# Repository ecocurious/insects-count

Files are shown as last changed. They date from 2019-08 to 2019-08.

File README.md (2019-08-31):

## Insektencounter
Ziel dieses Projekts ist die Entwicklung eines Geräts zur Erkennung und Zählung verschiedener Insektenarten.
Damit soll es dann möglich sein, die Artenvielfalt und deren Veränderung engmaschig und lokal zu erfassen. Zusammen mit anderen Umweltdaten kann so eine Karte erstellt werden. 

Dazu wurden zwei Verfahren ausgewählt, um die Insekten erkennen und somit auch zählen zu können.
- optisch mit Hilfe einer Kamera, die Erkennung erfolgt hier mit auf Insekten trainierter KI
- [Erkennung des Flügelschlags mit einem optischen Mikrofon](http://msei.github.io/insects-count/fluegelschlag.html)

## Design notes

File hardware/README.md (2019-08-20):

Insect Counter Hardware
=======================

## IR-Transmitter

PCB for modulated IR LED transmitter

## IR-Receiver

PCB to receive modulated IR signal

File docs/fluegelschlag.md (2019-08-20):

# Klassifizierung von Insekten an Hand des Flügelschlags

Insekten eines Typs und Geschlechts haben sehr ähnliche Flügelschläge in Winkel und Frequenz. Da ihre (unverletzten) Flügel auch ähnlich gebaut sind hören sie sich auch sehr ähnlich an (harmonische Oberwellen). Ausnahmen sind Männchen einiger Mosquitoarten, die in der Paarungszeit den Klang der Weibchen, das die umwerben, immitieren.
[Insect-flight](https://en.wikipedia.org/wiki/Insect_flight)

Der Flügelschlag kann mit verschiedenen Verfahren vermessen werden. Akustisch durch Schall oder Licht, Radar, Highspeedkamera mit Bildverarbeitung

[Spitzen, Jeroen & Takken, Willem. (2018). Keeping track of mosquitoes: A review of tools to track, record and analyse mosquito flight. Parasites & Vectors. 11. 10.1186/s13071-018-2735-6. ](https://parasitesandvectors.biomedcentral.com/articles/10.1186/s13071-018-2735-6)

### Akustisches Mikrofon
Die passive, schallbasierte Vermessung des Flügelschlags ist sehr störungsbehaftet außerhalb des Labors. Wind und Reflektionen von anderen Tieren erzeugen breitbandige Störungen, die schwer zu entfernen sind. Somit ist es schwer, das eigentliche Nutzsignal zu isolieren. Fledermäuse nutzen daher aktive Echolokation und Erkennung, indem sie ein definiertes Signal aussenden und dieses Muster mit dem empfangenen Signal überlagern, um das Nutzsignal vom Hintergrundgreräusch trennen zu können.Ähnlich funktionieren auch moderne Radarsysteme. Je nach Verhalten des ausgesandten Signals können unterschiedliche Charakteristika an Beute und Umgebung erkannt werden. [Animal-echolocation](https://en.wikipedia.org/wiki/Animal_echolocation)

### Optisches Mikrofon
Strahlt man Licht auf ein fliegendes Insekt, so hat der Flügelschlag Einfluss auf die Intensität des Lichts hinter dem Insekt, da durch den sich ändernden Anstellwinkel der Flügel mal mehr oder weniger Licht abgeschattet wird. Ebenso ist das auch mit dem reflektierten Licht. Diese Helligkeitsschwankungen können durch einen Photodetektor gemessen werden. Niederfrequente Änderungen, die durch Sonnenlicht oder die Bewegung des Körpers hervorgerufen werden,lassen sich gut ausfiltern. Das erzeugte Signal hat eine Bandbreite im einstelligen kHZ Bereich und kann so mit günstigen Mikrocontrollern erfasst und verarbeitet werden. 

Zu zeigen: 
* eventuell auch Erkennung auf µC möglich mit Bayes
* horizontale oder vertikale Messung robuster

[Chen, Y., Why, A., Batista, G., Mafra-Neto, A., Keogh, E. Flying Insect Detection and Classification with Inexpensive Sensors. J. Vis. Exp. (92), e52111, doi:10.3791/52111 (2014).](https://arxiv.org/abs/1403.2654v1)

[Keogh, E.,Naive Bayes Classifier](https://www.cs.ucr.edu/~eamonn/CE/Bayesian%20Classification%20withInsect_examples.pdf)

[MDPI and ACS Style
Sandrini Moraes, F.; Edson Nava, D.; Scheunemann, T.; Santos da Rosa, V. Development of an Optoelectronic Sensor for Detecting and Classifying Fruit Fly (Diptera: Tephritidae) for Use in Real-Time Intelligent Traps. Sensors 2019, 19, 1254.](https://www.mdpi.com/1424-8220/19/5/1254/htm)

[Potamitis I, Rigakis I, Fysarakis K (2015)
Insect Biometrics: Optoacoustic Signal Processing
and Its Applications to Remote Monitoring of McPhail
Type Traps. PLoS ONE 10(11): e0140474.
doi:10.1371/journal.pone.0140474](https://pdfs.semanticscholar.org/1b32/68c05733fc8ac109b37251a67e5672cd6d9b.pdf)

[Rigakis, Iraklis & Potamitis, Ilyas & Tatlas, Nicolaos-Alexandros & Livadaras, Ioannis & Ntalampiras, Stavros. (2019). A Multispectral Backscattered Light Recorder of Insects’ Wingbeats. Electronics. 8. 277. 10.3390/electronics8030277. ](https://www.mdpi.com/2079-9292/8/3/277/htm)

[Michael A B Deakin, Formulae for insect wingbeat frequency, Journal of Insect Science, Volume 10, Issue 1, 2010, 96](https://doi.org/10.1673/031.010.9601)

[I. Potamitis and I. Rigakis, "Large Aperture Optoelectronic Devices to Record and Time-Stamp Insects’ Wingbeats," in IEEE Sensors Journal, vol. 16, no. 15, pp. 6053-6061, Aug.1, 2016.
doi: 10.1109/JSEN.2016.2574762](https://ieeexplore.ieee.org/document/7482663)

### Radar

In der Radartechnik wurde die Erkennung eines Flugzeugtyps durch Vermessung der Turbinenschaufeln und deren Drehzahl oder die Erkennung von Personen anhand ihres Gangs entwickelt. Hierbei wird der Umstand ausgenutzt, dass Teile des zu vermessenden Objekts relativ zum Großteil des Objekts bewegen (Beine und Arme). Bewegt sich das zu vermessende Objekt ebenfalls, so überlagert sich die relative Bewegung mit der globalen Bewegung. Bei den häufig eigesetzten Dopplerradaren wird dies durch eine periodische Änderung der Ausgangsfrequenz deutlich. Dabei ist die Grundfrequenz proportional zur Fluggeschindigkeit, relativ zum Radar und die Periodendauer der Frequenzänderungen entspricht der relativen Bewegung. Diese Frequenzänderung wird auch als Microdoppler bezeichnet. 
Dieses Verfahren kann auch zur Erkennung des Flügelschlags verwendet werden. Da Radare empfindlich auf sie zu oder von ihnen weg bewegenden Objekten reagieren, sollte der Radar in der Flugebene des Insekts sein.
Auch hier muss das Nutzsignal herausgefiltert werden. Neben der Frequenzmodulation durch den Flügel kann auch die Phasenmodulation verwendet werden, da diese auch periodisch moduliert wird durch den Flügelschlag. Hierzu braucht man neben dem reellen in-Phasesignal noch das imaginäre Q-Signal des Radars. Günstige Geräte führen dies meist nicht nach außen. Auch die das Arbeitsfrequenzband hat einen Einfluss auf das Ergebnis.

[Wang, R., Hu, C., Fu, X., Long, T., & Zeng, T. (2017). Micro-Doppler measurement of insect wing-beat frequencies with W-band coherent radar. Scientific reports, 7(1), 1396. doi:10.1038/s41598-017-01616-4](https://www.ncbi.nlm.nih.gov/pmc/articles/PMC5431090/)

### Highspeed Bildverarbeitung

Die Aufnahme eines fliegenden Insekts mittels einer Highspeedkamera, lässt auch Rückschlüsse auf die Schlagfrequenz zu. Diese Kameras brauchen wegen der kurzen Belichtungszeit des Bilder eine ausreichend starke Beleuchtung. Auch sind diese Kameras und die Hardware zur Verarbeitung der Bilder vergleichsweise teurer als die oben genannten Methoden. Daher wird dieses Verfahren zunächst nicht weiter verfolgt.

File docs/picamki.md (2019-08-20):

# Insektenerkennung mit Kamera und KI

Hier soll mit Hilfe eines RaspberryPi und den dafür verfügbaren Kameras ein Insekt fotografiert und per KI charakterisiert werden.

## Aufbau

## Vorgehen

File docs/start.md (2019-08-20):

## Insektencounter
Ziel dieses Projekts ist die Entwicklung eines Geräts zur Erkennung und Zählung verschiedener Insektenarten.
Damit soll es dann möglich sein, die Artenvielfalt und deren Veränderung engmaschig und lokal erfassen zu können. Zusammen mit anderen Umweltdaten kann so eine Karte erstellt werden. Auch kann so die Ausbreitung invasiver Arten erfasst und verfolgt werden.

Dazu wurden zwei Verfahren ausgewählt, um die Insekten erkennen und somit auch zählen zu können.
- [optisch mit Hilfe einer Kamera, die Erkennung erfolgt hier mit auf Insekten trainierter KI](http://msei.github.io/insects-count/picamki.html)
- [Erkennung des Flügelschlags mit einem optischen Mikrofon](http://msei.github.io/insects-count/fluegelschlag.html)

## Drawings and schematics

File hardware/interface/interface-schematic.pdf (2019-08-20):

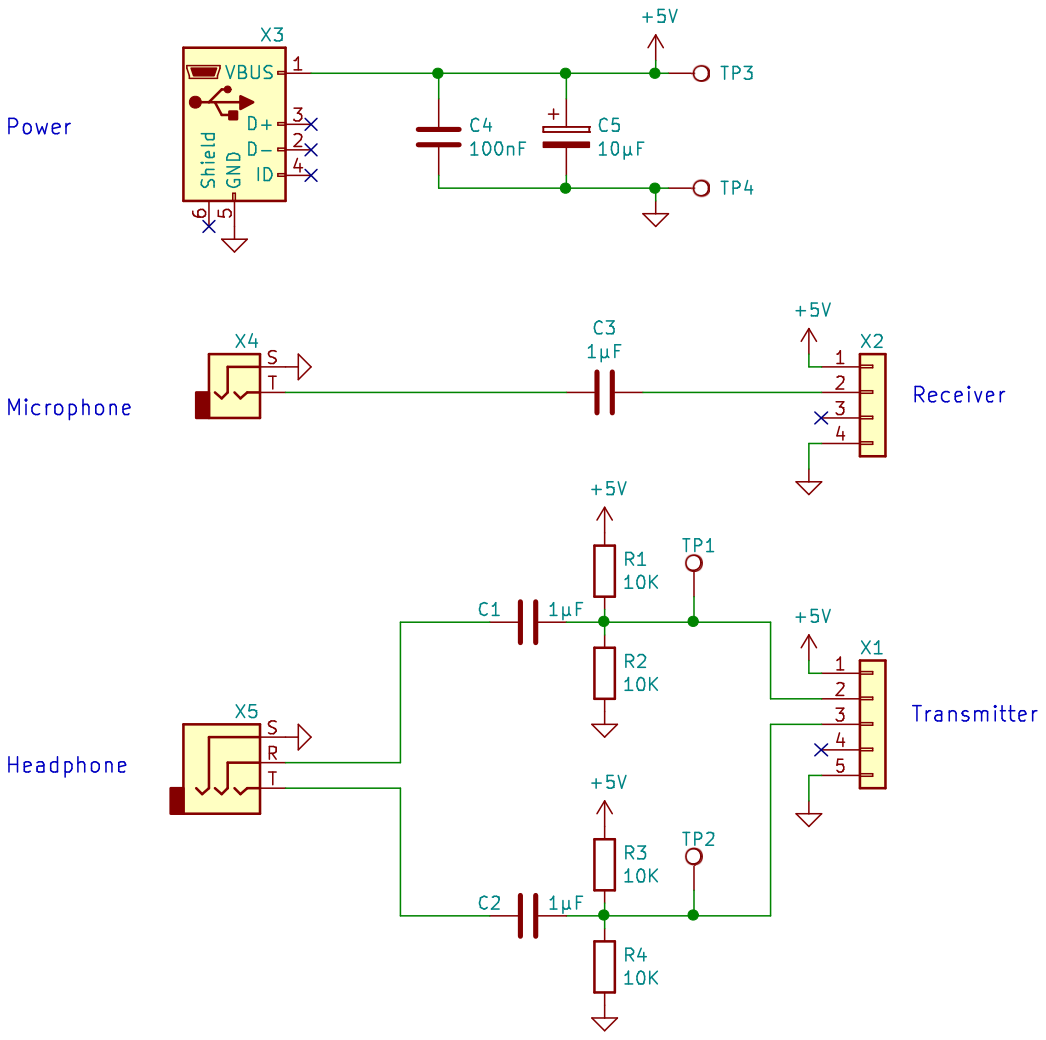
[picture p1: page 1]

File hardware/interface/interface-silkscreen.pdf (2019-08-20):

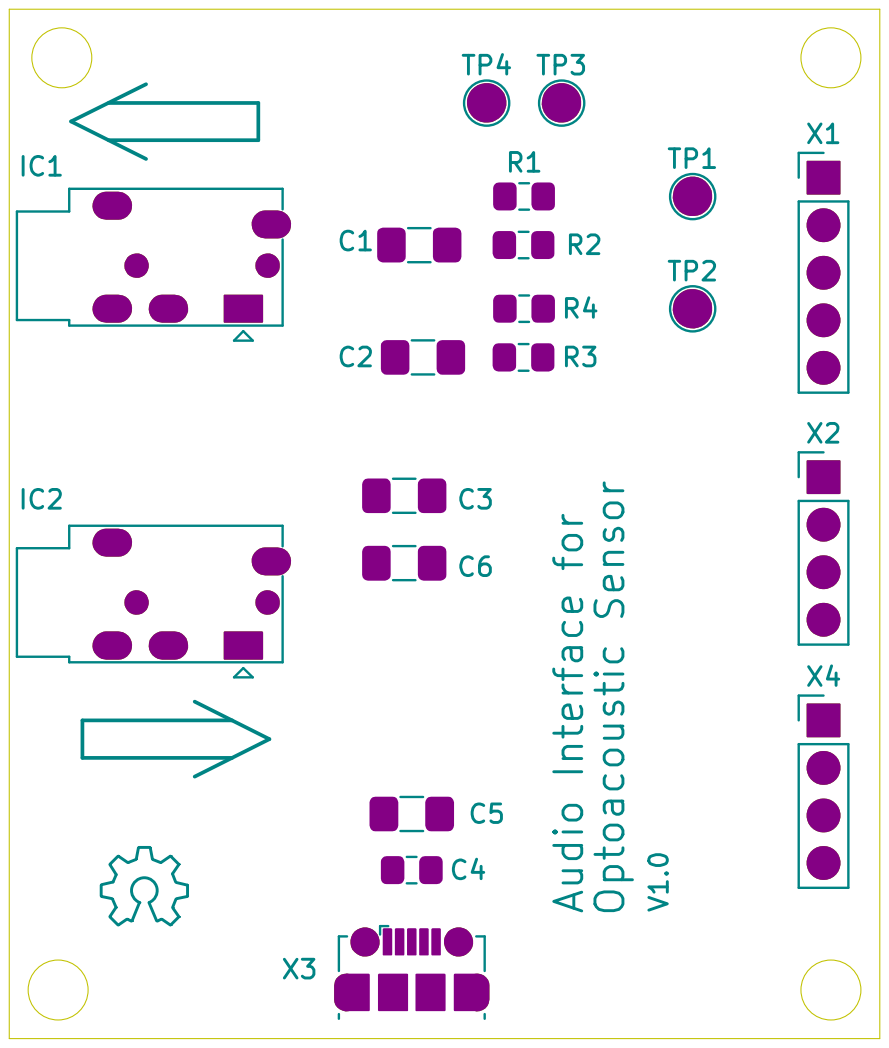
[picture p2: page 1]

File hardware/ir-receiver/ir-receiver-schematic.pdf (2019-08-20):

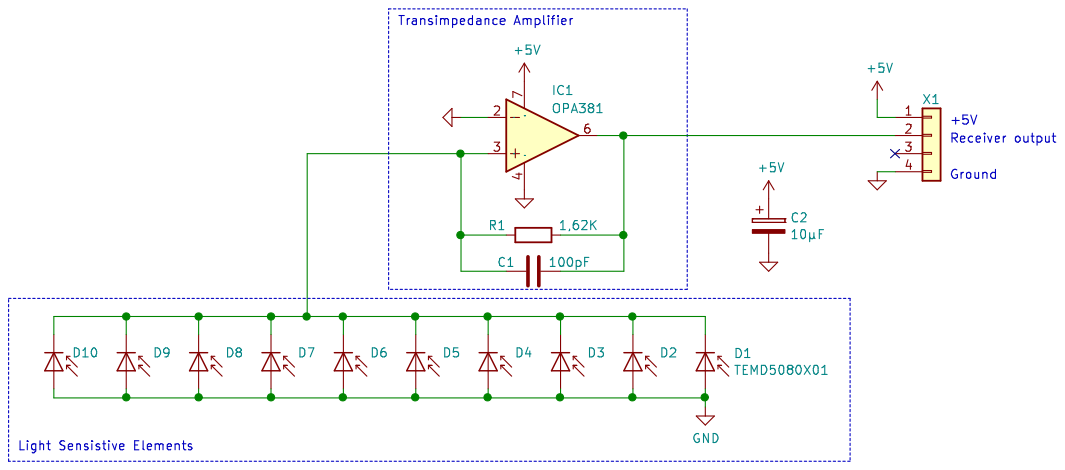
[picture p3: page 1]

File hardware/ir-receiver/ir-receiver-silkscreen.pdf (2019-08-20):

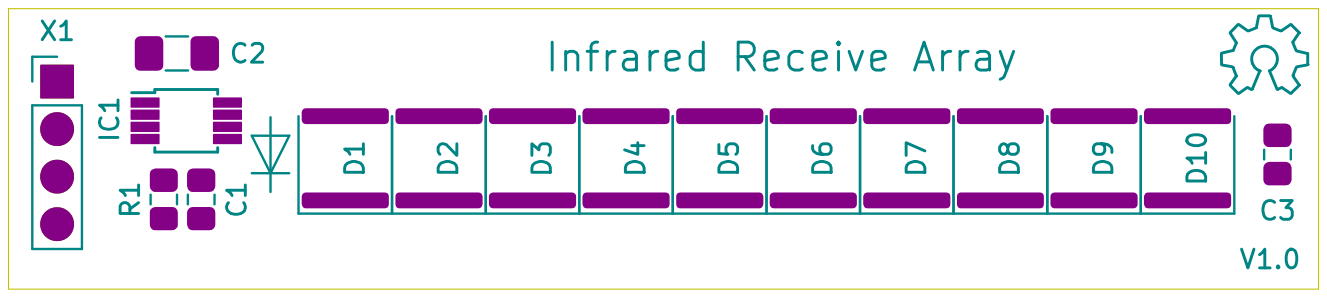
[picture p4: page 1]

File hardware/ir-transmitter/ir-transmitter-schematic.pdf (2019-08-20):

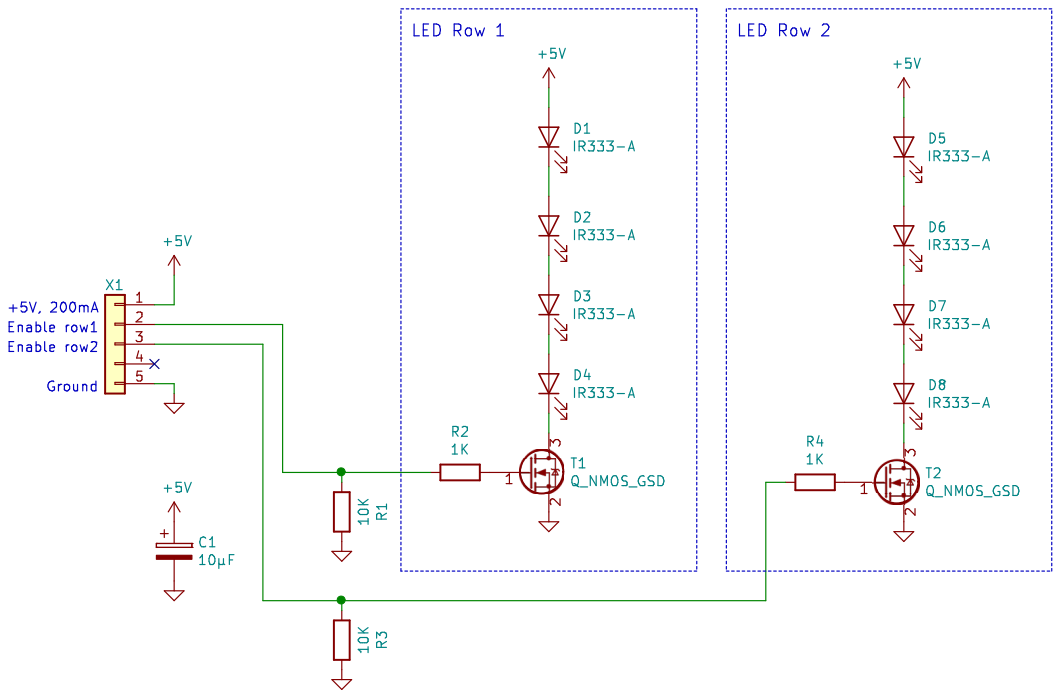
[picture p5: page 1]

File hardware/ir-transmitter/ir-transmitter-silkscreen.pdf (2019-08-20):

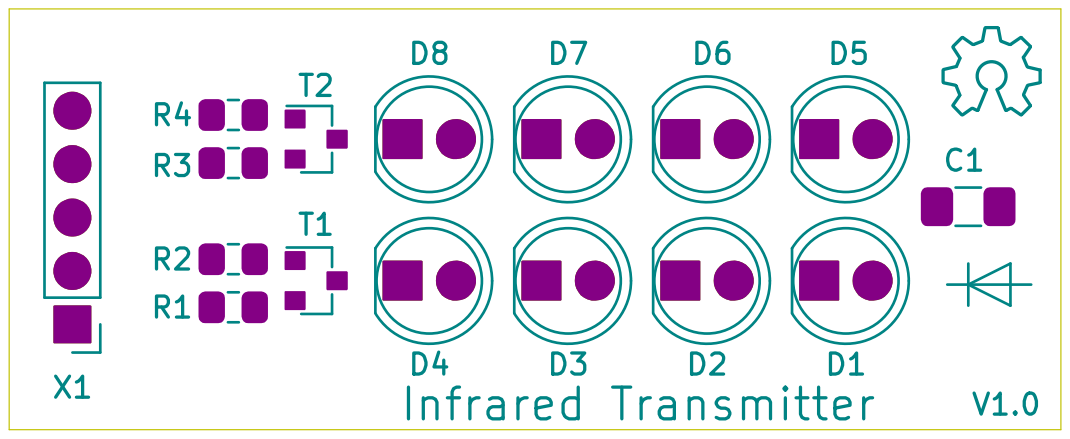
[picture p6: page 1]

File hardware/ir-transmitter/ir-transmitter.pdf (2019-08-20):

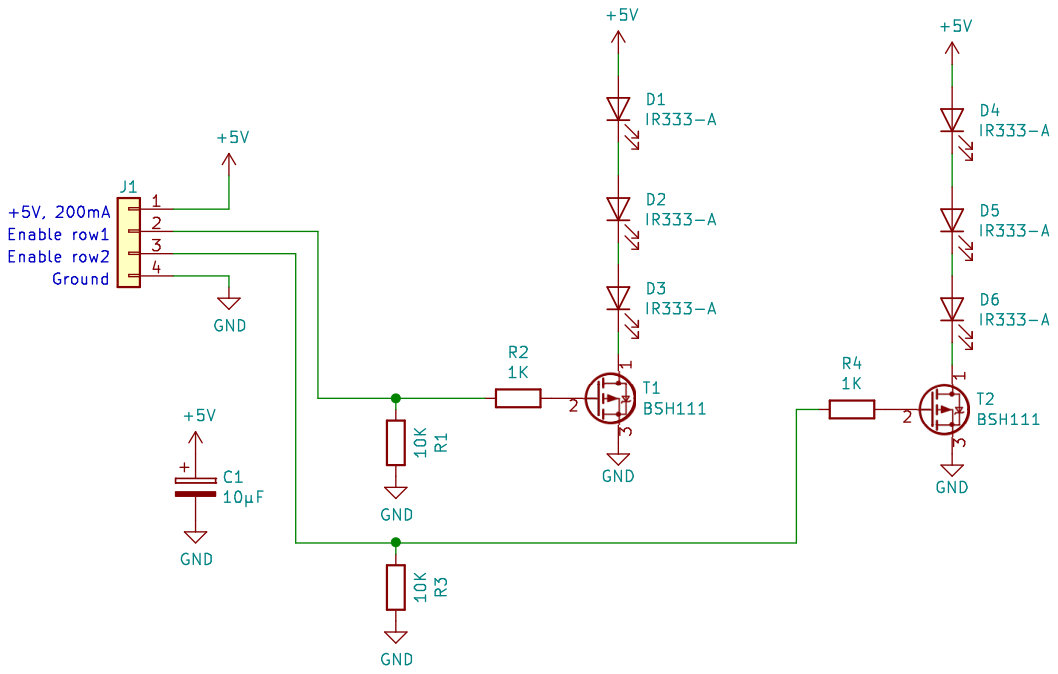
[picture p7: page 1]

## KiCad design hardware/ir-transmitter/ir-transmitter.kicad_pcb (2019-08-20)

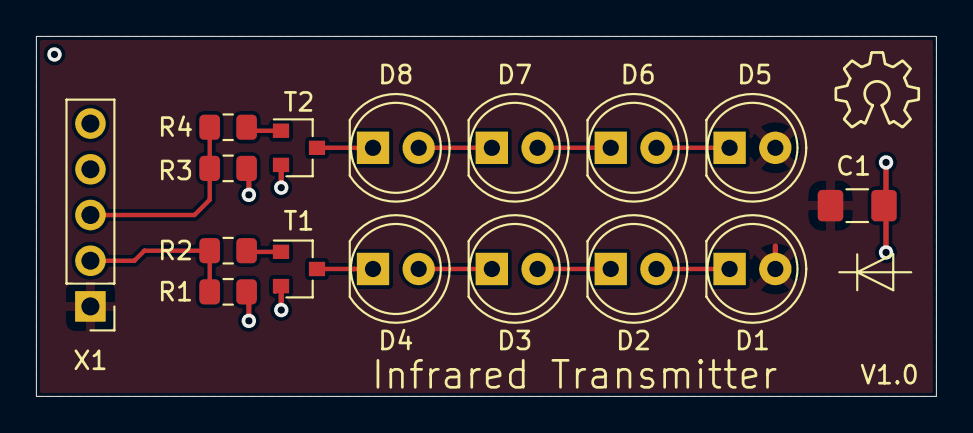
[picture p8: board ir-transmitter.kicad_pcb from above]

Board: 2 copper layers, 50.0 x 20.0 mm, 16 parts (0 on the bottom side), 14 nets.

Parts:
C1: 10µF; C_1206_3216Metric_Pad1.42x1.75mm_HandSolder
D1, D2, D3, D4, D5, D6, D7, D8: IR333-A; LED_D5.0mm
R1, R3: 10K; R_0805_2012Metric_Pad1.15x1.40mm_HandSolder
R2, R4: 1K; R_0805_2012Metric_Pad1.15x1.40mm_HandSolder
T1, T2: Q_NMOS_GSD; SOT-23
X1: Conn_01x05; PinHeader_1x05_P2.54mm_Vertical

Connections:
+5V: C1.1, D1.2, D5.2, X1.1
GND: C1.2, R1.1, R3.1, T1.2, T2.2, X1.5
unnamed: D1.1, D2.2
unnamed: D2.1, D3.2
unnamed: D3.1, D4.2
unnamed: D4.1, T1.3
unnamed: D5.1, D6.2
unnamed: D6.1, D7.2
unnamed: D7.1, D8.2
unnamed: D8.1, T2.3
unnamed: R1.2, R2.2, X1.2
unnamed: R2.1, T1.1
unnamed: R3.2, R4.2, X1.3
unnamed: R4.1, T2.1

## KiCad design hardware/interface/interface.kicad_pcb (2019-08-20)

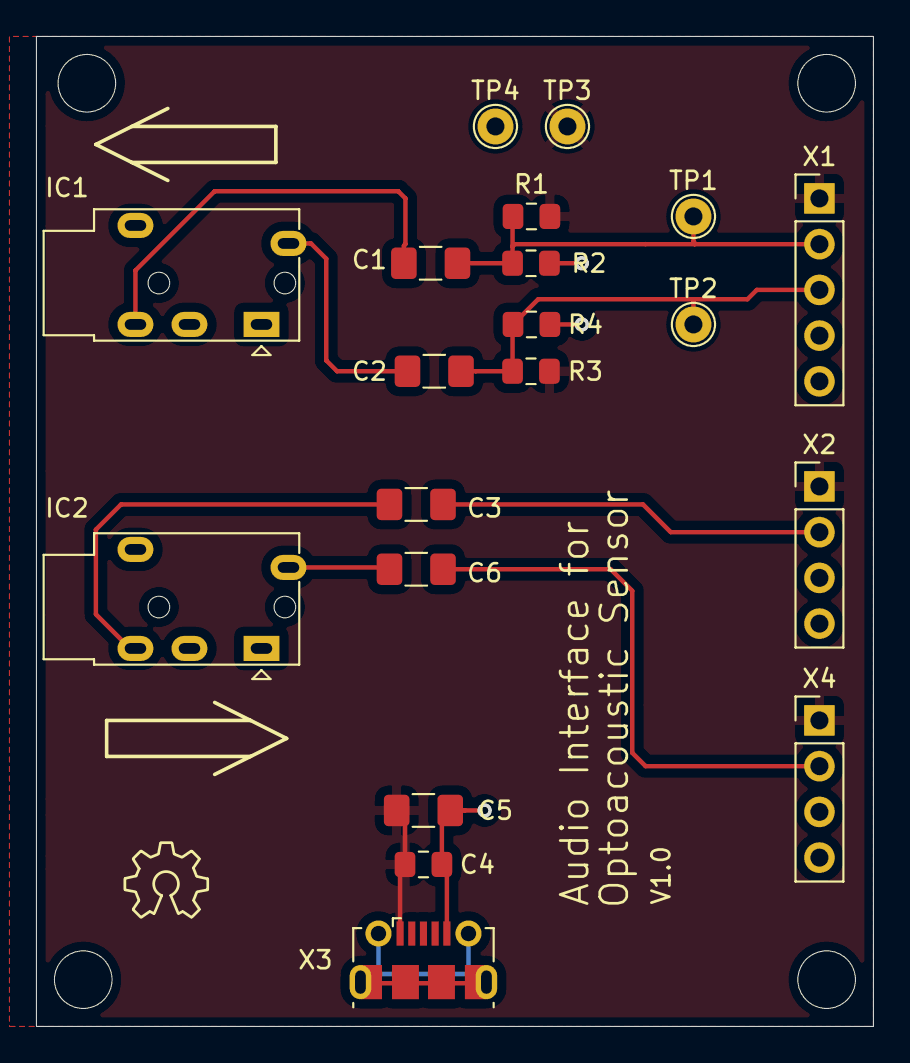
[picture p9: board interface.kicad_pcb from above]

Board: 2 copper layers, 46.5 x 55.0 mm, 20 parts (0 on the bottom side), 10 nets.

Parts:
C1, C2, C3, C6: 1µF; R_1206_3216Metric_Pad1.42x1.75mm_HandSolder
C4: 100nF; R_0805_2012Metric_Pad1.15x1.40mm_HandSolder
C5: 10µF; R_1206_3216Metric_Pad1.42x1.75mm_HandSolder
IC1, IC2: AudioJackPJ302E; Jack_3.5mm_PJ320E_Horizontal
R1, R2, R3, R4: 10K; R_0805_2012Metric_Pad1.15x1.40mm_HandSolder
TP1, TP2, TP3, TP4: TestPoint; TestPoint_THTPad_D2.0mm_Drill1.0mm
X1: Conn_01x05; PinHeader_1x05_P2.54mm_Vertical
X2, X4: Conn_01x04; PinHeader_1x04_P2.54mm_Vertical
X3: USB_B_Micro; USB_Micro-B_Molex-105017-0001

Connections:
+5V: C4.1, C5.1, R1.1, R3.1, TP3.1, X1.1, X2.1, X3.1, X4.1
GND: C4.2, C5.2, IC1.2, IC2.2, R2.2, R4.2, TP4.1, X1.5, X2.4, X3.5, X4.4
unnamed: C1.1, R1.2, R2.1, TP1.1, X1.2
unnamed: C1.2, IC1.3
unnamed: C2.1, R3.2, R4.1, TP2.1, X1.3
unnamed: C2.2, IC1.4
unnamed: C3.1, X2.2
unnamed: C3.2, IC2.3
unnamed: C6.1, X4.2
unnamed: C6.2, IC2.4

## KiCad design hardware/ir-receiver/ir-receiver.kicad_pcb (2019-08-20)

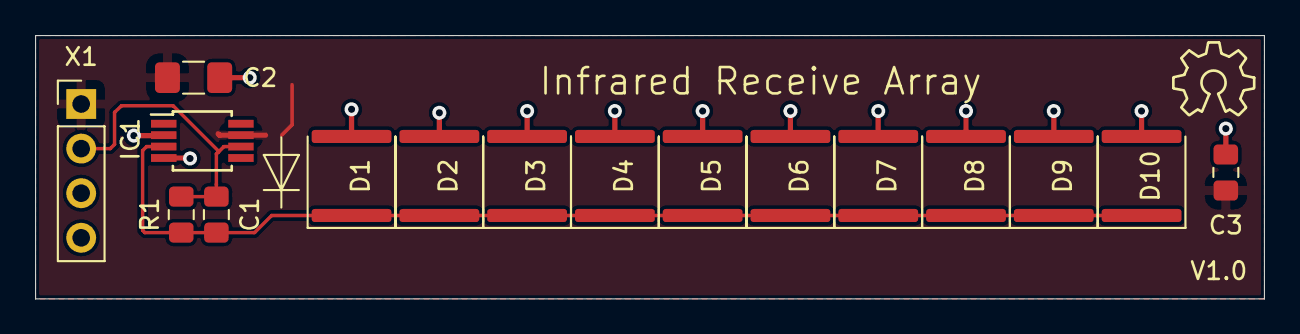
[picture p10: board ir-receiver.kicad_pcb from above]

Board: 2 copper layers, 70.0 x 15.0 mm, 16 parts (0 on the bottom side), 4 nets.

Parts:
C1: 100pF; C_0805_2012Metric_Pad1.15x1.40mm_HandSolder
C2: 10µF; C_1206_3216Metric_Pad1.42x1.75mm_HandSolder
C3: 100nF; C_0805_2012Metric_Pad1.15x1.40mm_HandSolder
D1, D2, D3, D4, D5, D6, D7, D8, D9, D10: TEMD5080X01; VISHAY-TEMD5080
IC1: OPA381; MSOP-8_3x3mm_P0.65mm
R1: 1,62K; R_0805_2012Metric_Pad1.15x1.40mm_HandSolder
X1: Conn_01x04; PinHeader_1x04_P2.54mm_Vertical

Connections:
+5V: C2.1, C3.1, IC1.7, X1.1
GND: C2.2, C3.2, D1.2, D2.2, D3.2, D4.2, D5.2, D6.2, D7.2, D8.2, D9.2, D10.2, IC1.2, IC1.4, X1.4
unnamed: C1.1, IC1.6, R1.2, X1.2
unnamed: C1.2, D1.1, D2.1, D3.1, D4.1, D5.1, D6.1, D7.1, D8.1, D9.1, D10.1, IC1.3, R1.1

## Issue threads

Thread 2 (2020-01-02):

Bürgerwissenschaften

Nordrunner01, 2020-01-02:
Moin

Wäre das nicht etwas für dieses/euer Projekt?: https://www.buergerschaffenwissen.de/

Gruß

ecocurious, 2020-02-04:
Hi, die Plattform kenn ich. Macht meines Erachtens Sinn, wenn wir schon ein bissle weiter in der Entwicklung sind, oder?

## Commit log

2019-07-02 Initial schematic for IR receiver and transmitter
    [ir-receiver.sch, ir-transmitter.sch]
2019-07-07 Finished layout
    [ir-receiver-B_Cu.gbr, ir-receiver-B_Mask.gbr, ir-receiver-B_Paste.gbr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]
2019-07-07 Add layout
    [ir-receiver.kicad_pcb, ir-transmitter.kicad_pcb, ir-transmitter.sch]
2019-07-07 Add gerber
    [ir-transmitter-B_Cu.gbr, ir-transmitter-B_Mask.gbr, ir-transmitter-B_Paste.gbr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]
2019-07-07 Add audio interface
    [interface-B_Cu.gbr, interface-B_Mask.gbr, interface-B_Paste.gbr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]
2019-07-07 Make receiver PCB two-sided
    [ir-receiver-B_Cu.gbr, ir-receiver-B_Mask.gbr, ir-receiver-B_Paste.gbr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]
2019-07-07 Double-sided PCBs
    [ir-receiver-B_Cu.gbr, ir-receiver-B_Mask.gbr, ir-receiver-B_Paste.gbr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]
2019-08-20 Moving Readme to github landing page
2019-08-20 Rename landing page so it's covered with the selected theme
